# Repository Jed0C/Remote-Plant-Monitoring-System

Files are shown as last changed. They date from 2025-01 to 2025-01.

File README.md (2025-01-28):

# Remote Plant Monitoring System

## Overview
The Remote Plant Monitoring System is designed to monitor the environmental conditions of plants remotely. It collects real-time data on temperature, humidity, and GPS location, and transmits this data using LoRa (Long Range) communication.

The system uses the ESP32 microcontroller, interfacing with the AM2315C I2C Temperature/Humidity Sensor, MTK3339 GPS Module, and RA-02 LoRa Module. This system is suitable for agricultural applications, where remote monitoring is essential to ensure optimal plant conditions.

## Features
- Temperature and Humidity Monitoring: Uses the AM2315C I2C sensor to measure temperature and humidity in the plant's environment.
- GPS Location: The MTK3339 GPS Module provides GPS coordinates, allowing for the tracking of plant location.
- Long-range Communication: The RA-02 LoRa Module enables communication over long distances (up to several kilometers), sending data to a base station or server.
- Low Power Consumption: Powered by a battery circuit, the system is designed for low power operation with deep sleep functionality for extended use in the field.
- Wireless Data Transmission: All data is transmitted wirelessly, making the system ideal for remote or hard-to-reach locations.
## Components Used
- ESP32-WROOM-32 Microcontroller: A versatile microcontroller with Wi-Fi and Bluetooth capabilities, acting as the central control unit.
- AM2315C Temperature/Humidity Sensor: An I2C-based sensor that measures temperature and humidity in the surrounding environment.
- MTK3339 GPS Module: A GPS module for acquiring the geographical location (latitude and longitude) of the monitoring system.
- RA-02 LoRa Module: A long-range wireless communication module using LoRaWAN technology, transmitting sensor data over great distances.

- Battery Circuit: A power supply system to power the entire setup, including charging and voltage regulation.

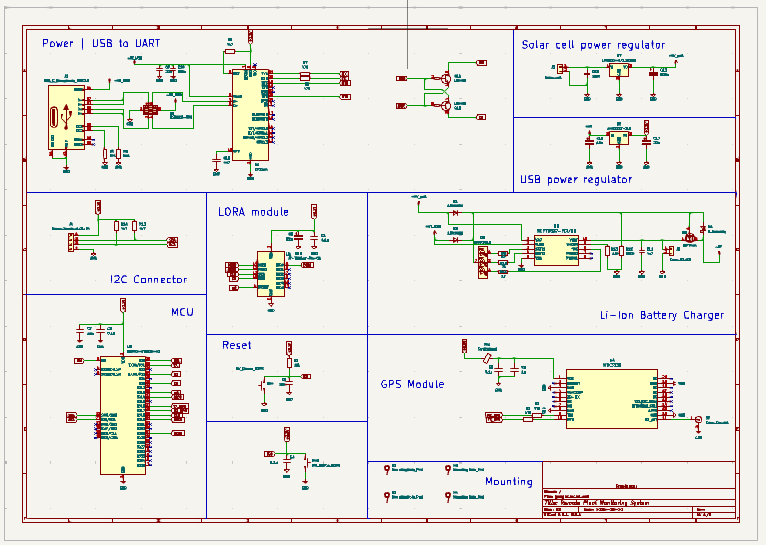
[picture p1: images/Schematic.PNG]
schematic

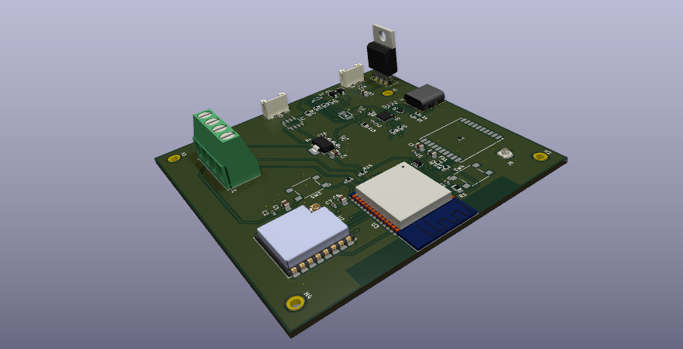
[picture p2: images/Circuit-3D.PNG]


## Installation
### Software Setup

Install Libraries:

- AM2315C Sensor: Install the Adafruit AHTx0 Library.
- GPS Module: Install TinyGPSPlus Library.
- LoRa Communication: Install the LoRa library.
In Arduino IDE, go to Sketch > Include Library > Manage Libraries and search for the necessary libraries to install.

## Usage
The ESP32 will initialize the sensor and GPS module.
The system will periodically collect humidity, and GPS coordinates data from the AM2315C sensor and the MTK3339 GPS module.
The collected data will be transmitted via the RA-02 LoRa Module to a receiver base station or a cloud server.
The data can be visualized or logged at the receiving end, such as an ESP32 with LoRa module or a cloud-based platform.
- Power Management
The system is designed to run on a solar cell and battery ,and uses deep sleep modes on the ESP32 to reduce power consumption during idle periods.

## Contributing
Feel free to fork this project and contribute to improvements or bug fixes. If you have suggestions or questions, open an issue on the repository.

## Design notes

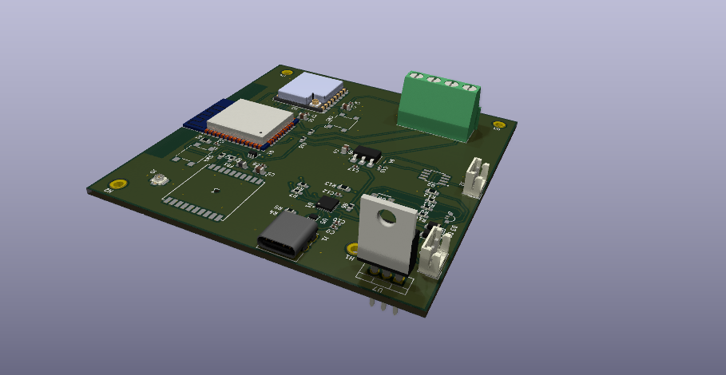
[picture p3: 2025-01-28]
images/Circuit-3D-2.PNG

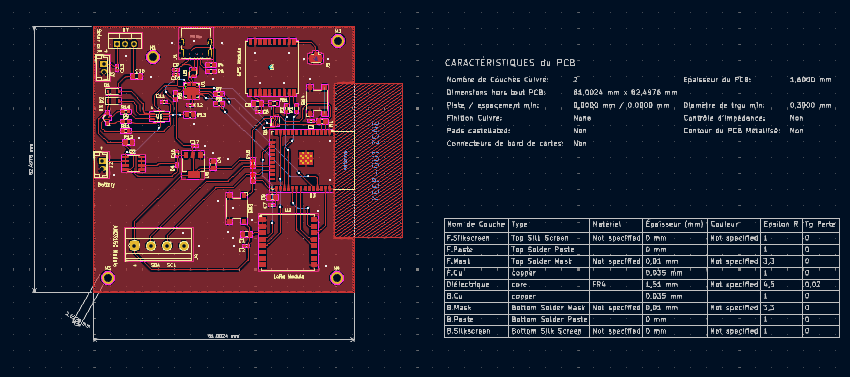
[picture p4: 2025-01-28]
images/PCB.PNG

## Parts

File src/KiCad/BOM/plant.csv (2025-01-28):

Id | Référence | Empreinte | Quantité | Désignation | Fournisseur et réf
1 | U6 | MSOP10_MC_MCH | 1 | MCP73837-FCI/UN
2 | U4 | PA1616S_ADA | 1 | MTK3339
3 | D2,D1 | D_SOD-123 | 2 | 1N4148W
4 | R10,R11,R9 | R_0603_1608Metric_Pad0.98x0.95mm_HandSolder | 3 | 1k
5 | R1,R13 | R_0805_2012Metric_Pad1.20x1.40mm_HandSolder | 2 | 10k
6 | J5 | U.FL_Hirose_U.FL-R-SMT-1_Vertical | 1 | Conn_Coaxial
7 | D3 | LED_Kingbright_APFA3010_3x1.5mm_Horizontal | 1 | APFA3010
8 | R14,R6,R15 | R_0603_1608Metric_Pad0.98x0.95mm_HandSolder | 3 | 4k7
9 | C11,C12 | C_0402_1005Metric_Pad0.74x0.62mm_HandSolder | 2 | 4u7
10 | J3 | JST_EH_B2B-EH-A_1x02_P2.50mm_Vertical | 1 | Solar_cell
11 | FB1 | L_0805_2012Metric | 1 | FerriteBead
12 | C6 | C_0402_1005Metric_Pad0.74x0.62mm_HandSolder | 1 | 1u
13 | R7,R2,R3,R8 | R_0603_1608Metric_Pad0.98x0.95mm_HandSolder | 4 | 470
14 | U8 | SOT-223-3_TabPin2 | 1 | AMS1117-3.3
15 | SW3,SW4 | SW_SPST_Omron_B3FS-100xP | 2 | SW_Omron_B3FS
16 | C15 | C_0805_2012Metric_Pad1.18x1.45mm_HandSolder | 1 | 100u
17 | U1 | QFN-24-1EP_4x4mm_P0.5mm_EP2.6x2.6mm | 1 | CP2104
18 | U5 | SOT-666 | 1 | USBLC6-2P6
19 | C17,C2,C9 | C_0402_1005Metric_Pad0.74x0.62mm_HandSolder | 3 | 22u
20 | C7,C16,C3 | C_0402_1005Metric_Pad0.74x0.62mm_HandSolder | 3 | 10u
21 | C8,C1,C5,C4 | C_0805_2012Metric_Pad1.18x1.45mm_HandSolder | 4 | 0.1u
22 | Q2 | IRF7404 | 1 | IRF7404
23 | Q1 | SOT-363_SC-70-6 | 1 | UMH3N
24 | U2 | Ai-Thinker-Ra-01-LoRa | 1 | Ai-Thinker-Ra-02
25 | J2 | JST_EH_B2B-EH-A_1x02_P2.50mm_Vertical | 1 | Conn_01x02
26 | R4,R5 | R_0603_1608Metric_Pad0.98x0.95mm_HandSolder | 2 | 5k1
27 | U7 | TO-220-3_Vertical | 1 | LM2931-5.0_TO220
28 | U3 | ESP32-WROOM-32 | 1 | ESP32-WROOM-32
29 | C10,C13 | C_0402_1005Metric_Pad0.74x0.62mm_HandSolder | 2 | 100n
30 | J1 | USB_C_Receptacle_GCT_USB4085 | 1 | USB_C_Receptacle_USB2.0
31 | J4 | TerminalBlock_Phoenix_MKDS-1,5-4-5.08_1x04_P5.08mm_Horizontal | 1 | Screw_Terminal_01x04
32 | D4 | D_0201_0603Metric | 1 | D_Schottky
33 | R12 | R_0805_2012Metric_Pad1.20x1.40mm_HandSolder | 1 | 100k

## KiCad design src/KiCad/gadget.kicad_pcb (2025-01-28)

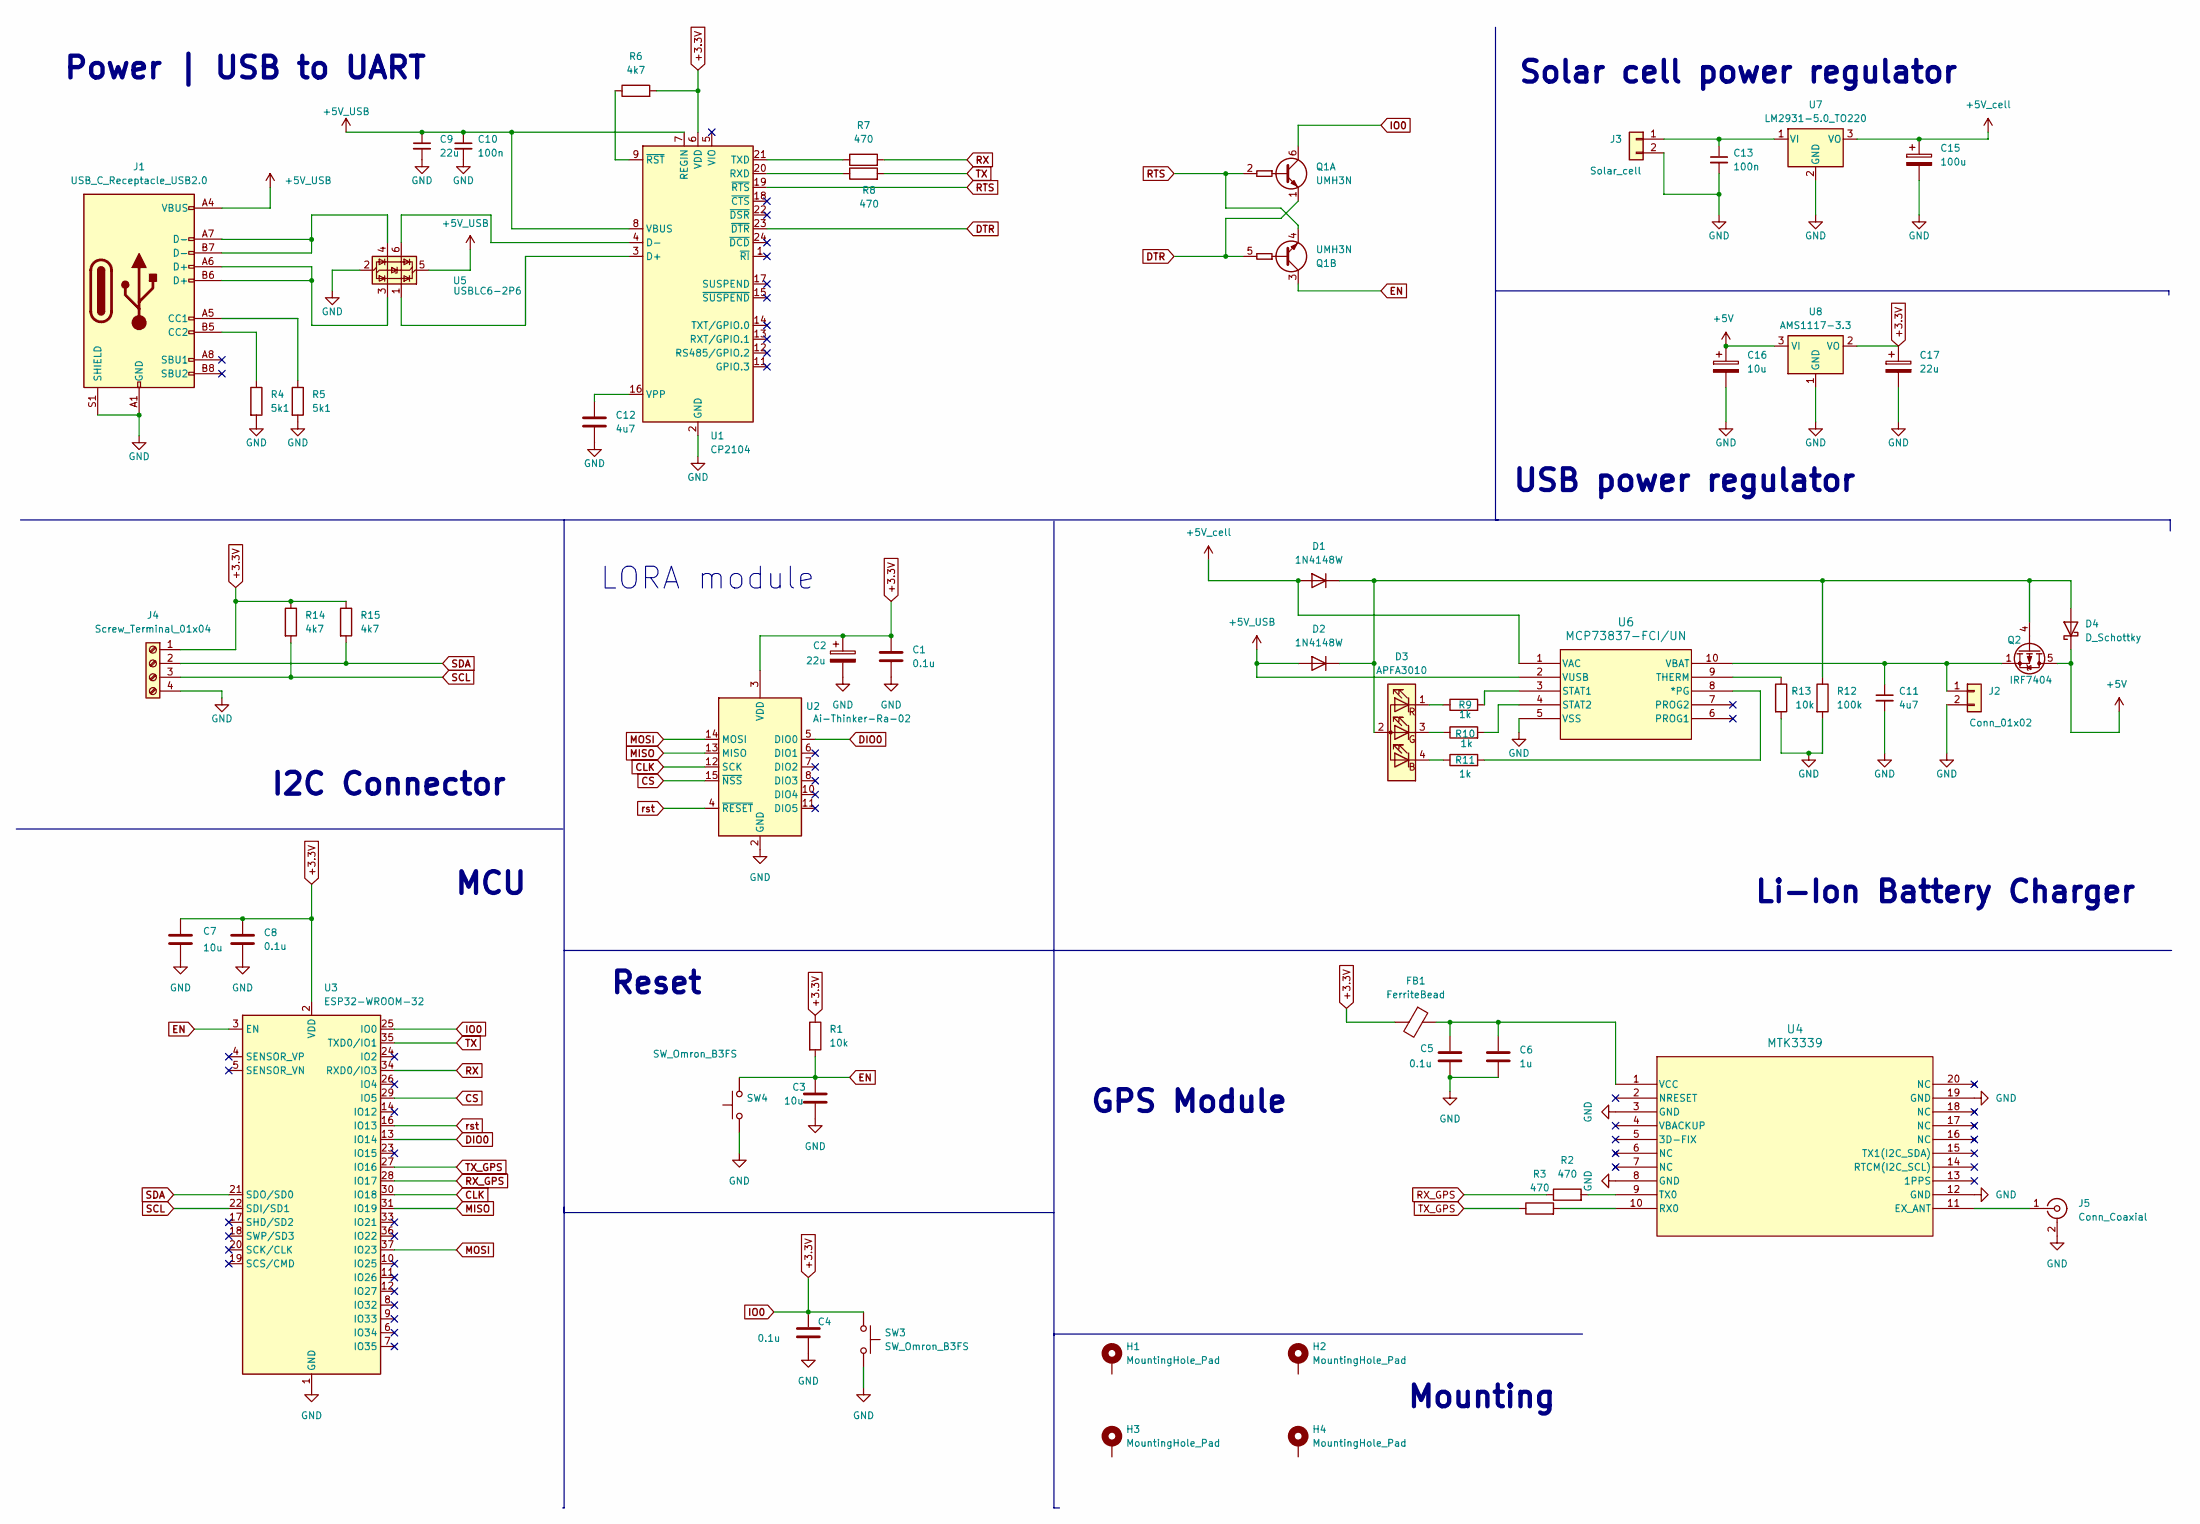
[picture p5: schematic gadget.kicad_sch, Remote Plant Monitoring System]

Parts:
C1, C4, C5, C8: 0.1u; C_0805_2012Metric_Pad1.18x1.45mm_HandSolder
C2, C9, C17: 22u; C_0402_1005Metric_Pad0.74x0.62mm_HandSolder
C3, C7, C16: 10u; C_0402_1005Metric_Pad0.74x0.62mm_HandSolder
C6: 1u; C_0402_1005Metric_Pad0.74x0.62mm_HandSolder
C10, C13: 100n; C_0402_1005Metric_Pad0.74x0.62mm_HandSolder
C11, C12: 4u7; C_0402_1005Metric_Pad0.74x0.62mm_HandSolder
C15: 100u; C_0805_2012Metric_Pad1.18x1.45mm_HandSolder
D1, D2: 1N4148W; D_SOD-123
D3: APFA3010; LED_Kingbright_APFA3010_3x1.5mm_Horizontal
D4: D_Schottky; D_0201_0603Metric
FB1: FerriteBead; L_0805_2012Metric
H1, H2, H3, H4: MountingHole_Pad; MountingHole_2.2mm_M2_DIN965_Pad
J1: USB_C_Receptacle_USB2.0; USB_C_Receptacle_GCT_USB4085
J2: Conn_01x02; JST_EH_B2B-EH-A_1x02_P2.50mm_Vertical
J3: Solar_cell; JST_EH_B2B-EH-A_1x02_P2.50mm_Vertical
J4: Screw_Terminal_01x04; TerminalBlock_Phoenix_MKDS-1,5-4-5.08_1x04_P5.08mm_Horizont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
J5: Conn_Coaxial; U.FL_Hirose_U.FL-R-SMT-1_Vertical
Q1: UMH3N; SOT-363_SC-70-6
Q2: IRF7404
R1, R13: 10k; R_0805_2012Metric_Pad1.20x1.40mm_HandSolder
R2, R3, R7, R8: 470; R_0603_1608Metric_Pad0.98x0.95mm_HandSolder
R4, R5: 5k1; R_0603_1608Metric_Pad0.98x0.95mm_HandSolder
R6, R14, R15: 4k7; R_0603_1608Metric_Pad0.98x0.95mm_HandSolder
R9, R10, R11: 1k; R_0603_1608Metric_Pad0.98x0.95mm_HandSolder
R12: 100k; R_0805_2012Metric_Pad1.20x1.40mm_HandSolder
SW3, SW4: SW_Omron_B3FS; SW_SPST_Omron_B3FS-100xP
U1: CP2104; QFN-24-1EP_4x4mm_P0.5mm_EP2.6x2.6mm
U2: Ai-Thinker-Ra-02; Ai-Thinker-Ra-01-LoRa
U3: ESP32-WROOM-32
U4: MTK3339; PA1616S_ADA
U5: USBLC6-2P6; SOT-666
U6: MCP73837-FCI/UN; MSOP10_MC_MCH
U7: LM2931-5.0_TO220; TO-220-3_Vertical
U8: AMS1117-3.3; SOT-223-3_TabPin2

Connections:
+3.3V: C1.1, C2.1, C4.1, C7.1, C8.1, C17.1, FB1.2, J4.1, Q1.6 (C1), R1.1, R6.2, R14.1, R15.1, SW3.1, U1.6 (VDD), U2.3 (VDD), U3.2 (VDD), U3.25 (IO0), U8.2 (VO)
+5V: C16.1, D4.1 (K), Q2.5 (D), Q2.6 (D), Q2.7 (D), Q2.8 (D), U8.3 (VI)
+5V_USB: C9.1, C10.1, D2.2 (A), J1.A4 (VBUS), J1.A9 (VBUS), J1.B4 (VBUS), J1.B9 (VBUS), U1.7 (REGIN), U1.8 (VBUS), U5.5 (VBUS), U6.2 (VUSB)
+5V_cell: C15.1, D1.2 (A), U6.1 (VAC), U7.3 (VO)
CLK: U2.12 (SCK), U3.30 (IO18)
CS: U2.15 (~NSS), U3.29 (IO5)
DIO0: U2.5 (DIO0), U3.13 (IO14)
DTR: Q1.1 (E1), Q1.5 (B2), U1.23 (~DTR)
EN: C3.1, Q1.3 (C2), R1.2, SW4.2, U3.3 (EN)
GND: C1.2, C2.2, C3.2, C4.2, C5.2, C6.2, C7.2, C8.2, C9.2, C10.2, C11.2, C12.2, C13.2, C15.2, C16.2, C17.2, J1.A1 (GND), J1.A12 (GND), J1.B1 (GND), J1.B12 (GND), J1.S1 (SHIELD), J2.2, J3.2, J4.4, J5.2 (Ext), R4.2, R5.2, R12.2, R13.2, SW3.2, SW4.1, U1.2 (GND), U1.25 (GND), U2.1 (GND), U2.2 (GND), U2.9 (GND), U2.16 (GND), U3.1 (GND), U3.15 (GND), U3.38 (GND), U3.39 (GND), U4.3 (GND), U4.8 (GND), U4.12 (GND), U4.19 (GND), U5.2 (GND), U6.5 (VSS), U7.2 (GND), U8.1 (GND)
MISO: U2.13 (MISO), U3.31 (IO19)
MOSI: U2.14 (MOSI), U3.37 (IO23)
unnamed: D1.1 (K), D2.1 (K), D3.2 (A), D4.2 (A), Q2.4 (G), R12.1
unnamed: D3.4 (B), R11.1
unnamed: D3.3 (G), R10.1
unnamed: D3.1 (R), R9.1
unnamed: J1.A5 (CC1), R5.1
unnamed: J1.B5 (CC2), R4.1
unnamed: J1.A6 (D+), J1.B6 (D+), U5.3 (I/O2)
unnamed: J1.A7 (D-), J1.B7 (D-), U5.4 (I/O2)
unnamed: C11.1, J2.1, Q2.1 (S), Q2.2 (S), Q2.3 (S), U6.10 (VBAT)
unnamed: C13.1, J3.1, U7.1 (VI)
unnamed: J5.1 (In), U4.11 (EX_ANT)
unnamed: U1.3 (D+), U5.1 (I/O1)
unnamed: U1.4 (D-), U5.6 (I/O1)
unnamed: R8.1, U1.20 (RXD)
unnamed: R7.1, U1.21 (TXD)
unnamed: C12.1, U1.16 (VPP)
unnamed: R6.1, U1.9 (~RST)
unnamed: R3.2, U4.10 (RX0)
unnamed: R2.2, U4.9 (TX0)
unnamed: C5.1, C6.1, FB1.1, U4.1 (VCC)
unnamed: R11.2, U6.8 (*PG)
unnamed: R9.2, U6.3 (STAT1)
unnamed: R10.2, U6.4 (STAT2)
unnamed: R13.1, U6.9 (THERM)
RTS: Q1.2 (B1), Q1.4 (E2), U1.19 (~RTS)
RX: R7.2, U3.34 (RXD0/IO3)
RX_GPS: R2.1, U3.28 (IO17)
SCL: J4.3, R14.2, U3.22 (SDI/SD1)
SDA: J4.2, R15.2, U3.21 (SDO/SD0)
TX: R8.2, U3.35 (TXD0/IO1)
TX_GPS: R3.1, U3.27 (IO16)
rst: U2.4 (~RESET), U3.16 (IO13)

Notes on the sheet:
I2C Connector
Reset
MCU
Power | USB to UART
Mounting
GPS Module
Li-Ion Battery Charger
LORA module
Solar cell power regulator
USB power regulator

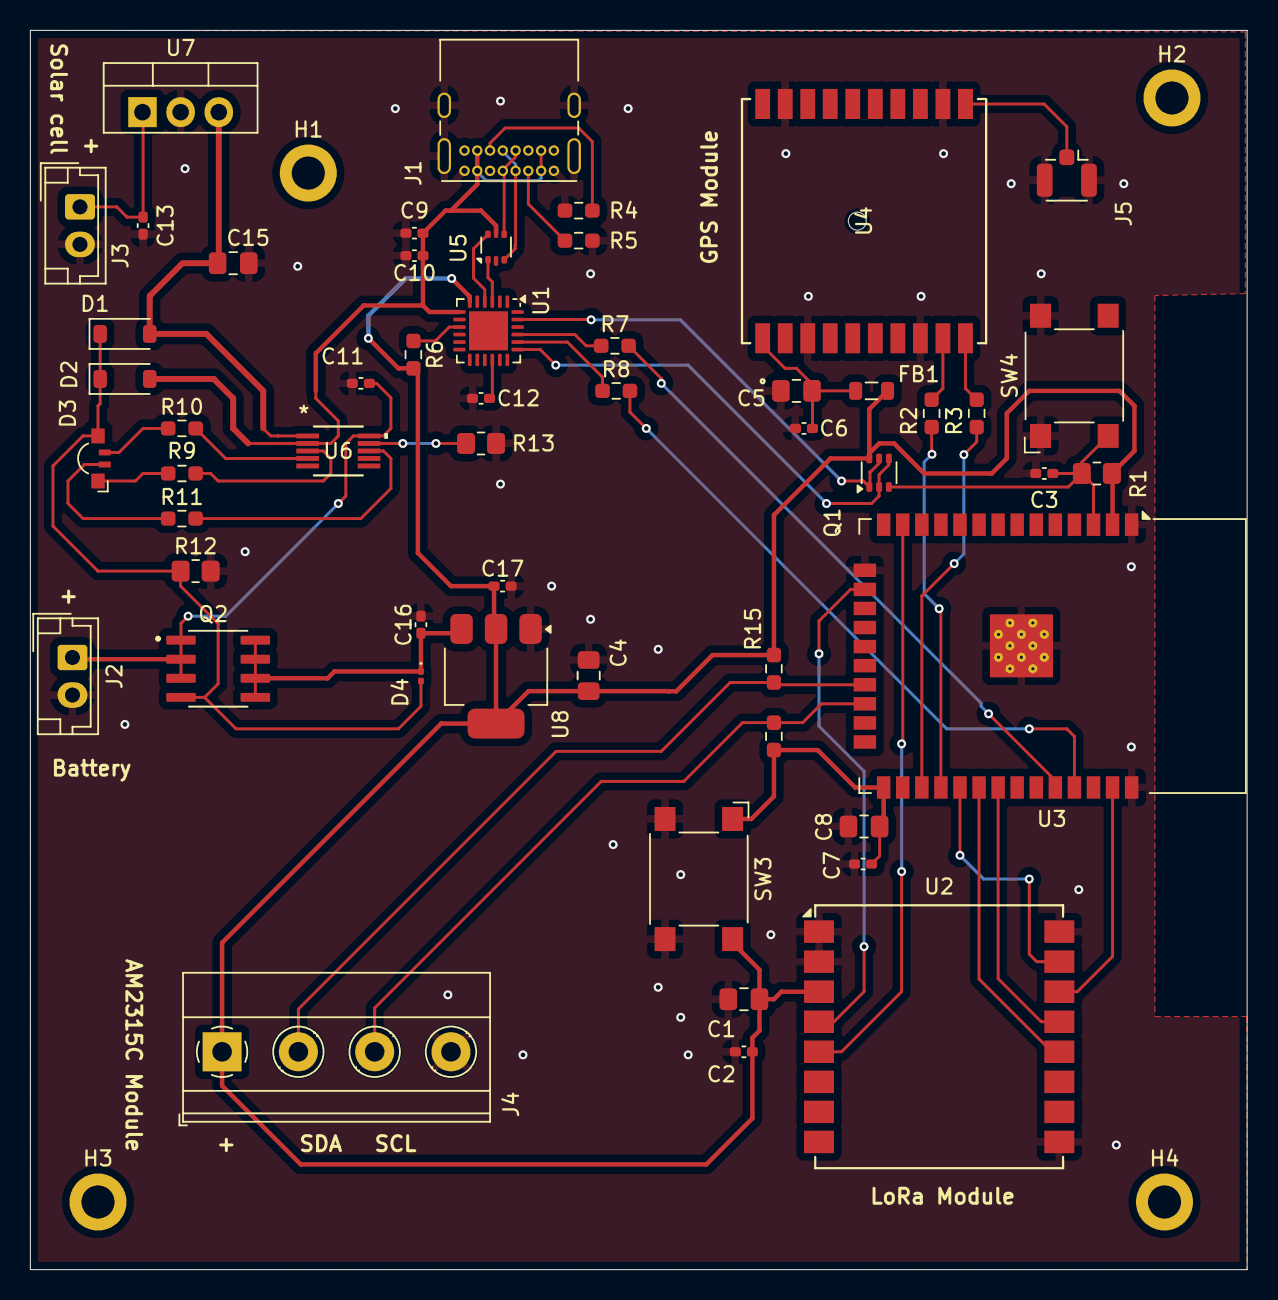
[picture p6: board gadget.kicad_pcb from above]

Board: 2 copper layers, 81.0 x 82.5 mm, 57 parts (0 on the bottom side), 44 nets.

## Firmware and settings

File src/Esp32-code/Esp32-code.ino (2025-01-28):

#include <SPI.h>
#include <LoRa.h>
#include <TinyGPSPlus.h>
#include <HardwareSerial.h>
#include <Adafruit_AHTX0.h>

#define uS_TO_S_FACTOR 1000000  // Conversion factor for micro seconds to seconds 
#define TIME_TO_SLEEP  600  //time to sleep in seconds (10 min)

TinyGPSPlus gps;
HardwareSerial SerialGPS(1);

Adafruit_AHTX0 aht;
Adafruit_Sensor *aht_humidity;

//GPS pins
const int GPS_RX = 17; // RX pin for GPS
const int GPS_TX = 16; // TX pin for GPS

//lora pins
const int CS = 5;
const int RST = 13;
const int DIO0 = 14;


void sendData(){
  String Data ="";

  //read from moisure sensor
  sensors_event_t moisureData;
  aht_humidity->getEvent(&moisureData);
  
  //read from gps
  while (SerialGPS.available()){
    gps.encode(SerialGPS.read());
  }

  if (gps.location.isValid()){
    Data = "Lat: " + String(gps.location.lat(), 6) + ", Lng: " + String(gps.location.lng(), 6) + ", ";
    Data = Data + "Date: " + String(gps.date.day()) + "/" + String(gps.date.month()) + "/" + String(gps.date.year());
    Data = Data + "  Time: " + String(gps.time.hour()) + ":" + String(gps.time.minute()) + ":" + String(gps.time.second());
    Data = Data + String(moisureData.relative_humidity);
  }

//send data
  LoRa.beginPacket();
  LoRa.print(Data);
  LoRa.endPacket();
  
}


void setup() {
  
  //Serial.begin(115200); // Serial for debugging
  SerialGPS.begin(9600, SERIAL_8N1, GPS_RX, GPS_TX);

  aht.begin();
  aht_humidity = aht.getHumiditySensor();

  LoRa.setPins(CS, RST, DIO0);//setup LoRa module
  LoRa.begin(868E6); //Lora frequency used in Tunisia
  LoRa.setSyncWord(0xA0);//sync word with the receiver ( word can be into range 0 to 0xFF)
  
  sendData();

  esp_sleep_enable_timer_wakeup(TIME_TO_SLEEP * uS_TO_S_FACTOR); //sleep 10 minutes
  esp_deep_sleep_start();

}

void loop() {//nothing here
}
